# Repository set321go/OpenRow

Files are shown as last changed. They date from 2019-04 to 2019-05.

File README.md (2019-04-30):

# OpenRow

A project to design an build an open source rowing computer. This project was born from the idea that I would rather throw something cheaper than a cell phone into the water, a secondary driver was how expensive existing options are given they are in effect a specialized pedometer.

## Goals

1. Hardware and software for an acceleration based rowing computer similar in functionality to a variety of apps available for phones.
2. Speaker/Headset module integration (module provides headset functionality existing computer provides rowing data), which fits into existing headset amplifier form factor.
3. GPS & Bluetooth
4. Fitness platform compatability.

## Secondary Goals

1. Floats
2. Impeller Integration

## Design

This is purely a personal hobby project at some point it may make sense to use a funding platform to do a medium sized run with assembly but there are no plans for this. I have no background in EE.

### Circuit

I have used kicad 5. Its free and open source, you can use whatever tools you wish but you need to ensure the files in the project remain comatible with kicad.

### PCB

The current design is built to [JLCPCB](https://jlcpcb.com/capabilities/Capabilities) 2 layer design rules, I have no solution for providing multiple pcb's which would allow designs for multiple fabrictors. It is likely in the future to ease the design of RF components I will move to a 4 layer design.

### Assembly

Stencil and hand assembly with a homebrew toaster oven reflow setup for prototyping and testing.

### Case

3D printed - in progress

### Software

In progress

## Commercial Use

If you use this project commercially reference to its usage on the consumer device is desired but not required under the licensing terms.

## Getting Involved

If you would like to get involved please get in touch.

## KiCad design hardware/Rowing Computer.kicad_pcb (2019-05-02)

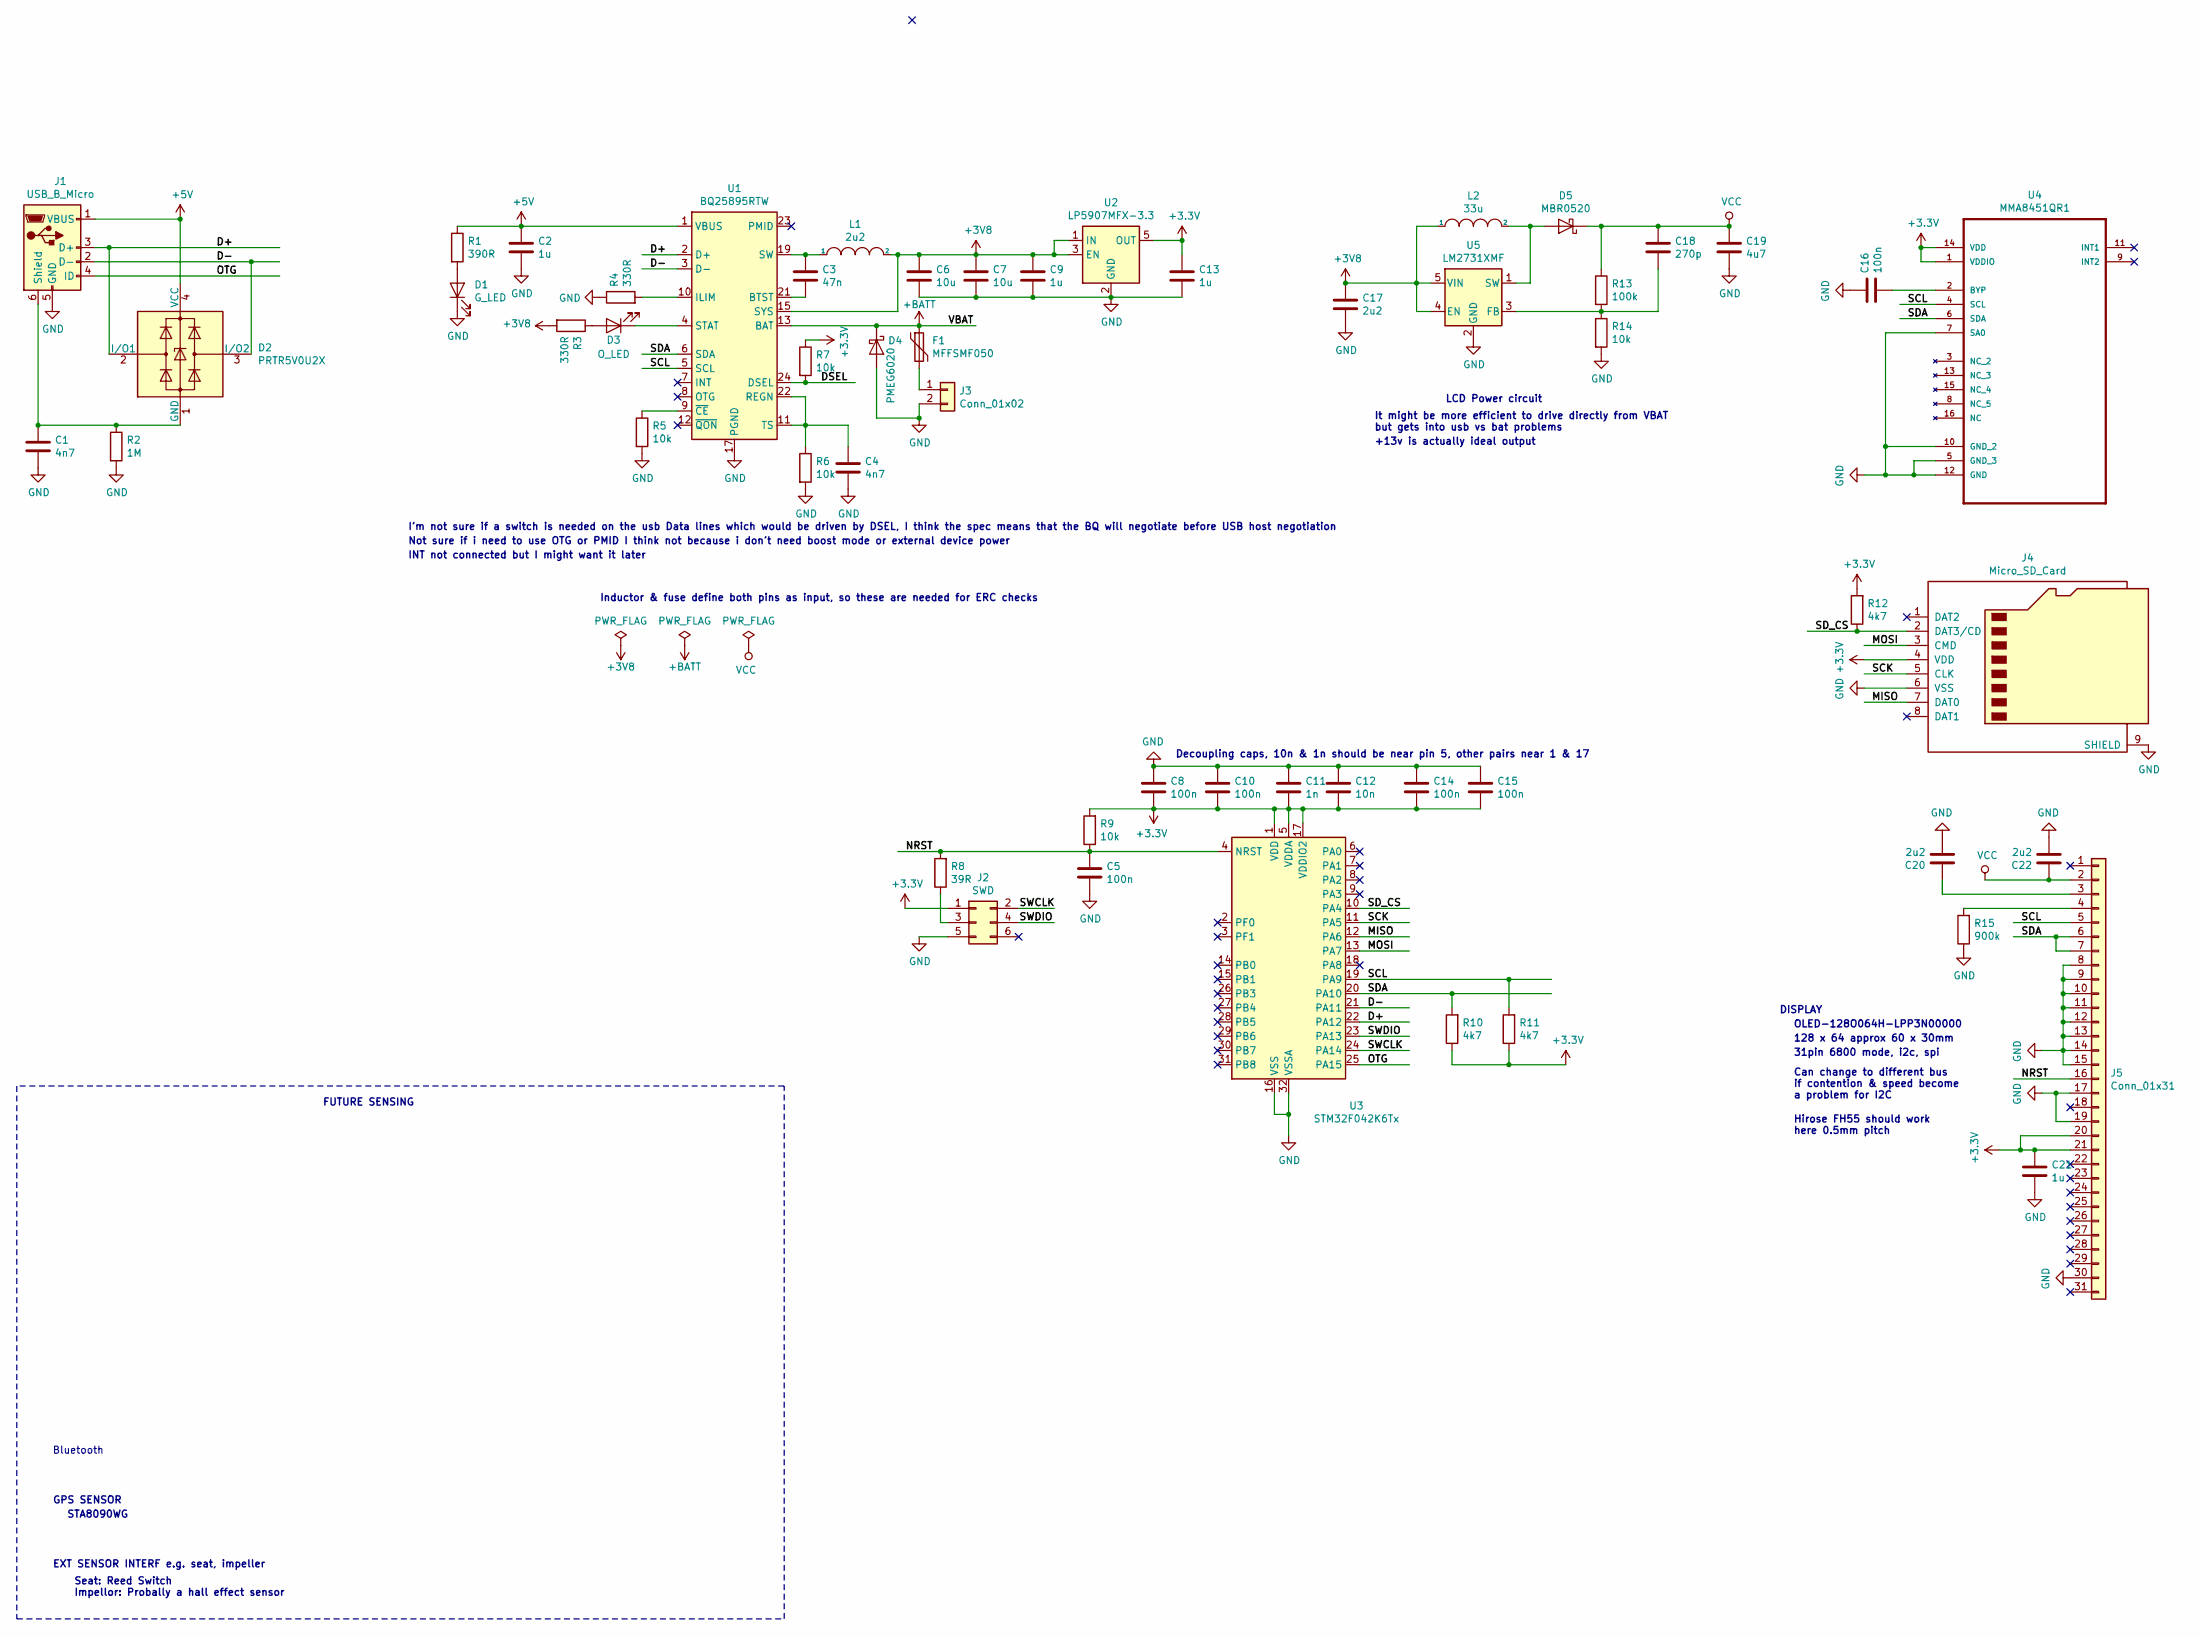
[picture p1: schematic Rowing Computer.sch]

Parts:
C1, C4: 4n7; C_0402_1005Metric
C2, C9, C13, C21: 1u; C_0402_1005Metric
C3: 47n; C_0402_1005Metric
C5, C8, C10, C14, C15, C16: 100n; C_0402_1005Metric
C6, C7: 10u; C_0603_1608Metric
C11: 1n; C_0402_1005Metric
C12: 10n; C_0402_1005Metric
C17, C20, C22: 2u2; C_0402_1005Metric
C18: 270p; C_0402_1005Metric
C19: 4u7; C_0603_1608Metric
D1: G_LED; LED_0402_1005Metric
D2: PRTR5V0U2X; SOT-143
D3: O_LED; LED_0402_1005Metric
D4: PMEG6020; D_SOD-123
D5: MBR0520; D_SOD-123
F1: MFFSMF050; Fuse_0402_1005Metric
J1: USB_B_Micro; USB_Micro-B_Molex_47346-0001
J2: SWD; PinHeader_2x03_P1.27mm_Vertical_SMD
J3: Conn_01x02; JST_PH_S2B-PH-SM4-TB_1x02-1MP_P2.00mm_Horizontal
J4: Micro_SD_Card; microSD_HC_Hirose_DM3D-SF
J5: Conn_01x31; FPC_31
L1: 2u2; L_0805_2012Metric
L2: 33u; L_0805_2012Metric
R1: 390R; R_0402_1005Metric
R2: 1M; R_0402_1005Metric
R3, R4: 330R; R_0402_1005Metric
R5, R6, R7, R9, R14: 10k; R_0402_1005Metric
R8: 39R; R_0402_1005Metric
R10, R11, R12: 4k7; R_0402_1005Metric
R13: 100k; R_0402_1005Metric
R15: 900k; R_0402_1005Metric
U1: BQ25895RTW; Texas_S-PWQFN-N24_EP2.7x2.7mm_ThermalVias
U2: LP5907MFX-3.3; SOT-23-5
U3: STM32F042K6Tx; LQFP-32_7x7mm_P0.8mm
U4: MMA8451QR1; QFN50P300X300X100-16N
U5: LM2731XMF; SOT-23-5

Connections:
+3V3: C8.2, C10.2, C11.2, C12.2, C13.1, C14.2, C15.2, C21.1, J2.1, J4.4 (VDD), J5.20, J5.21, R7.1, R9.2, R10.1, R11.1, R12.2, U2.5 (OUT), U3.1 (VDD), U3.5 (VDDA), U3.17 (VDDIO2), U4.1 (VDDIO), U4.14 (VDD)
+3V8: C6.1, C7.1, C9.1, C17.1, L1.2, L2.1, R3.2, U1.15 (SYS), U1.16 (SYS), U2.1 (IN), U2.3 (EN), U5.4 (EN), U5.5 (VIN)
+5V: C2.1, D2.4 (VCC), J1.1 (VBUS), R1.1, U1.1 (VBUS)
+BATT: D4.1 (K), F1.1, U1.13 (BAT), U1.14 (BAT)
/D+: D2.2 (I/O1), J1.3 (D+), U1.2 (D+), U3.22 (PA12)
/D-: D2.3 (I/O2), J1.2 (D-), U1.3 (D-), U3.21 (PA11)
/DSEL: R7.2, U1.24 (DSEL)
/MISO: J4.7 (DAT0), U3.12 (PA6)
/MOSI: J4.3 (CMD), U3.13 (PA7)
/NRST: C5.1, J5.16, R8.2, R9.1, U3.4 (NRST)
/OTG: J1.4 (ID), U3.25 (PA15)
/SCK: J4.5 (CLK), U3.11 (PA5)
/SCL: J5.5, R11.2, U1.5 (SCL), U3.19 (PA9), U4.4 (SCL)
/SDA: J5.6, J5.7, R10.2, U1.6 (SDA), U3.20 (PA10), U4.6 (SDA)
/SD_CS: J4.2 (DAT3/CD), R12.1, U3.10 (PA4)
/SWCLK: J2.2, U3.24 (PA14)
/SWDIO: J2.4, U3.23 (PA13)
GND: C1.2, C2.2, C4.2, C5.2, C6.2, C7.2, C8.1, C9.2, C10.1, C11.1, C12.1, C13.2, C14.1, C15.1, C16.1, C17.2, C19.2, C20.2, C21.2, C22.2, D1.1 (K), D4.2 (A), J1.5 (GND), J2.5, J3.2, J4.6 (VSS), J4.9 (SHIELD), J5.8, J5.9, J5.10, J5.11, J5.12, J5.13, J5.14, J5.15, J5.17, J5.19, J5.30, R2.2, R4.1, R5.2, R6.2, R14.2, R15.1, U1.17 (PGND), U1.18 (PGND), U1.25 (PGND), U2.2 (GND), U3.16 (VSS), U3.32 (VSSA), U4.5 (GND_3), U4.7 (SA0), U4.10 (GND_2), U4.12 (GND), U5.2 (GND)
unnamed: C1.1, D2.1 (GND), J1.6 (Shield), R2.1
unnamed: C3.1, L1.1, U1.19 (SW), U1.20 (SW)
unnamed: C3.2, U1.21 (BTST)
unnamed: C4.1, R6.1, U1.11 (TS), U1.22 (REGN)
unnamed: C16.2, U4.2 (BYP)
unnamed: C18.2, R13.2, R14.1, U5.3 (FB)
unnamed: C20.1, J5.3
unnamed: D1.2 (A), R1.2
unnamed: D3.1 (K), U1.4 (STAT)
unnamed: D3.2 (A), R3.1
unnamed: D5.2 (A), L2.2, U5.1 (SW)
unnamed: F1.2, J3.1
unnamed: J2.3, R8.1
unnamed: J5.4, R15.2
unnamed: R4.2, U1.10 (ILIM)
unnamed: R5.1, U1.9 (~CE)
VCC: C18.1, C19.1, C22.1, D5.1 (K), J5.2, R13.1

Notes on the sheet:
I’m not sure if a switch is needed on the usb Data lines which would be driven by DSEL, I think the spec means that the BQ will negotiate before USB host negotiation
Not sure if i need to use OTG or PMID I think not because i don’t need boost mode or external device power
INT not connected but I might want it later
Decoupling caps, 10n & 1n should be near pin 5, other pairs near 1 & 17
Inductor & fuse define both pins as input, so these are needed for ERC checks
GPS SENSOR
EXT SENSOR INTERF e.g. seat, impeller
DISPLAY
OLED-128O064H-LPP3N00000
128 x 64 approx 60 x 30mm
31pin 6800 mode, i2c, spi
LCD Power circuit
It might be more efficient to drive directly from VBAT but gets into usb vs bat problems
+13v is actually ideal output
Can change to different bus if contention & speed become a problem for I2C
Seat: Reed Switch Impellor: Probally a hall effect sensor
STA8090WG
FUTURE SENSING
Hirose FH55 should work here 0.5mm pitch
Bluetooth

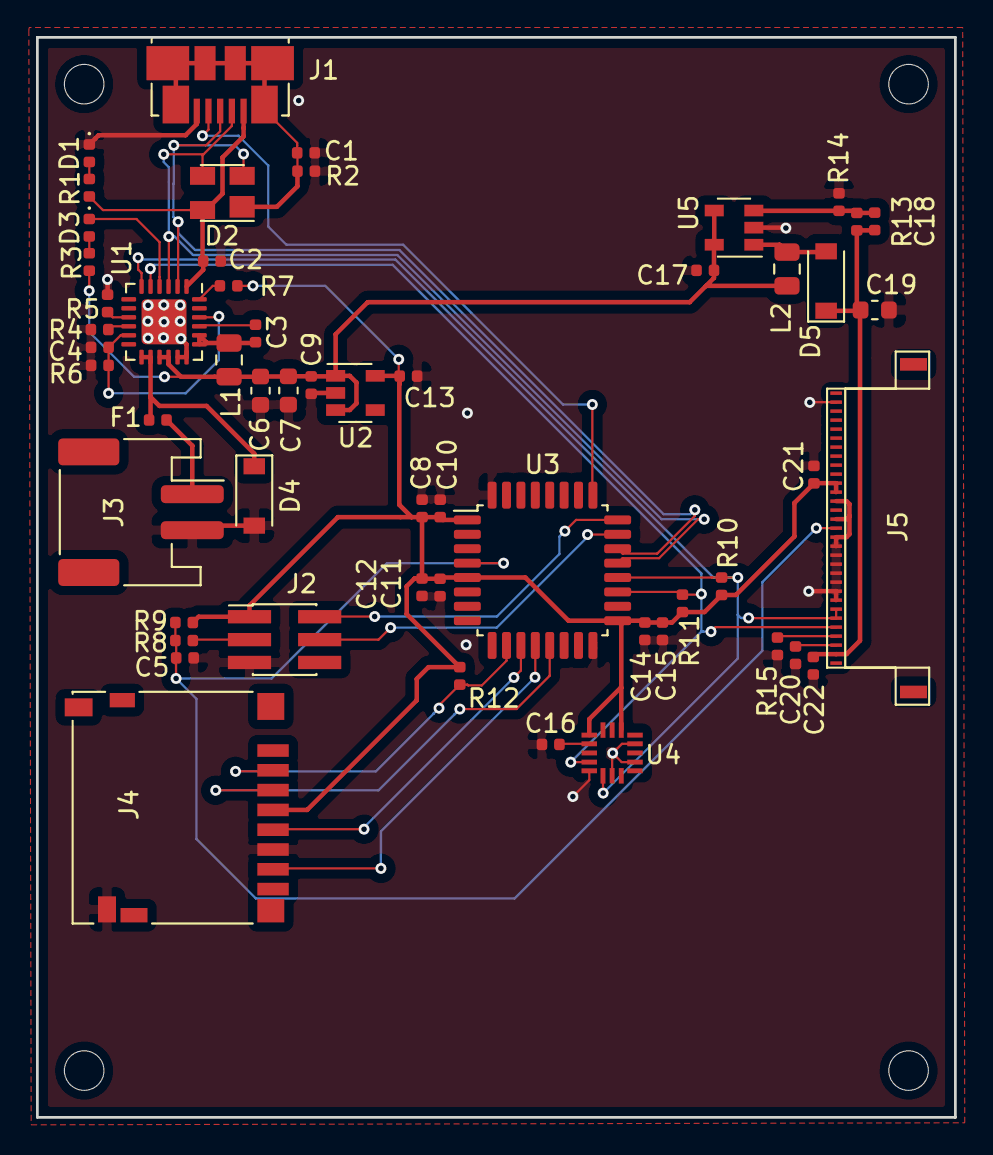
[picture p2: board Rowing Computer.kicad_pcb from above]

Board: 2 copper layers, 51.0 x 60.0 mm, 55 parts (0 on the bottom side), 35 nets.
